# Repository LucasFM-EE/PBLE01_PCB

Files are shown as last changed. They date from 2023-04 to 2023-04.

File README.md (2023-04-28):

# PBLE01_PCB

Project designed for the discipline: Project Based Learning 01.

# Requirements
In this project, the board must match these requirements: 

### 1. Power Supply: 
- Support voltage input of 7V to 12V (DC);
- Provide regulated output of 5V;
- Use a LED to indicate that the board is powered.

### 2. Processing:
- Use a PIC18F4550 as a unit of processing and control;
- Use a pin header compatible with the ICSP standard, to program the microcontroller;
- Use a push-button to reset the microcontroller.

### 3. User interaction:
- Have a keyboard, composed by 5 push-buttons;
- Have a LCD display, which its luminosity is controlled by a trimmer;
- Have at least 4 LED's, which are able to signalize different states of the MCU;
- Have a potentiometer, which is used to provide analog data.

### 4. Peripherals
- Use a Real-Time Clock(RTC) - MCP7940;
- Contain 2 pairs of differential analog inputs(4 analog inputs). Each pair must provide a signal between 0V and 3V for the microcontroller; 
- Contain a analog output, made by a PWM signal;
- Contain a pin header that has the reference signal(GND), the power supply signal(VCC) and the microcontroller pins that aren't being used.

### 5. Communication
- Use a USB-Serial converter(MCP2200), to allow serial communication with the board.

# Functional Diagram
The following image shows a functional diagram of the board: 
Diagrama_PBLE01_english

# Board sections 
The following image shows the board, divided by the sections mentioned above: 
Board_sections

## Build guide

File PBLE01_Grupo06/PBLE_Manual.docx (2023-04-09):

PBLE01

Co-projeto de produtos eletrônicos

Manual

Grupo 6

# 1 Identificação dos integrantes

André Luís Oliveira de Almeida – 2019008624
João Roberto da Silva Couto - 2018000944

Lucas Ferreira Machado - 2019000537

# 2 Introdução

O objetivo da disciplina era certamente nos incluir no ramo do mercado de trabalho para projetos, protótipos e lançamentos de PCIs (placas de circuito impresso) e ideias correlacionadas, por promover uma experiência de mercado de trabalho, com o maior número possível de detalhes ao ponto que a disciplina em si não ensina quase nada novo, pois foi visto o que se requere no projeto em períodos anteriores.

As principais atividades a serem desenvolvidas durante o transcorrer da disciplina são o projeto da placa de circuito impresso, o desenvolvimento de programa embarcado de validação e a elaboração da documentação de projeto, etapas que não devem seguir um planejamento de inícios e términos, com etapas sendo discutidas e aprimoradas ao mesmo tempo, como se observa no desenho abaixo:

Figura 1 - Diagrama de avanço de tarefas

A etapa de projeto da placa de circuito ainda pode ser subdividida nas etapas de elaboração do esquema elétrico e de elaboração da PCI.

a documentação de projeto, a etapa que aqui vos instrui, a ser desenvolvido consiste em um manual a partir do qual é possível confeccionar e validar a placa de circuito impresso projetada. Para tanto, tal documento deve pormenorizar características do circuito elaborado, como seu esquema elétrico, suas características elétricas, os passos para sua validação bem como a relação de seus componentes e os fornecedores para estes.

Dizem que o engenheiro é aquele que aplica os conhecimentos dos cientistas, então este projeto, e consequentemente esta disciplina é a oportunidade perfeita para isso.

# 3 Esquema elétrico

A atividade de elaboração de esquema elétrico consiste em desenvolver a representação do circuito eletroeletrônicos relativo à placa de circuito impresso em projeto. Essa atividade costuma ser realizada por meio de ferramentas de desenvolvimento gráficas. Em linhas gerais, por meio dessas ferramentas, são elencados (e representados) os componentes eletrônicos discretos a fazerem parte da placa de circuito impresso em projeto e a interconexão entre eles.

## 3.1 Requisitos

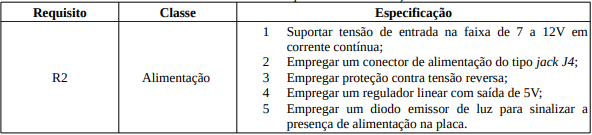
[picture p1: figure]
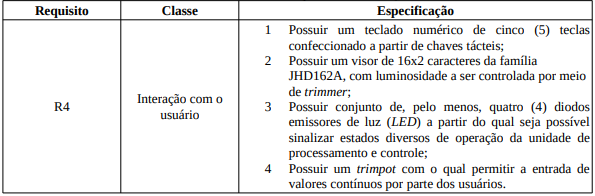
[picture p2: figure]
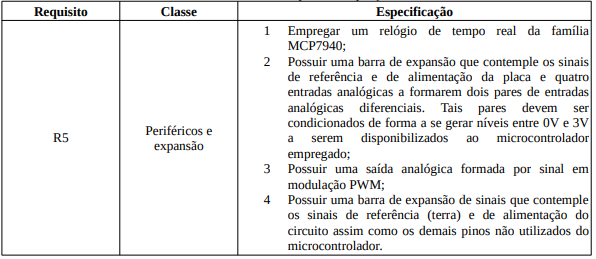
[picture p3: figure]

## 3.2 Circuito

O dispositivo almejado deve permitir, como principal meta, a interação entre diversas entradas e saídas com a unidade de processamento e os subcircuitos necessários para a efetivar a requisição do usuário.

Dentre entradas, algumas diretamente vindas do usuário (como o teclado), outras pré-definidas por estes (as entradas analógicas), outras vindas de terceiros (diferenciais) e ainda uma entrada do próprio dispositivo (RTC).

Dentre saídas, existem as que tanto visam informar o usuário (sinais de estados e LCD) quanto exportar um resultado (saída analógica).

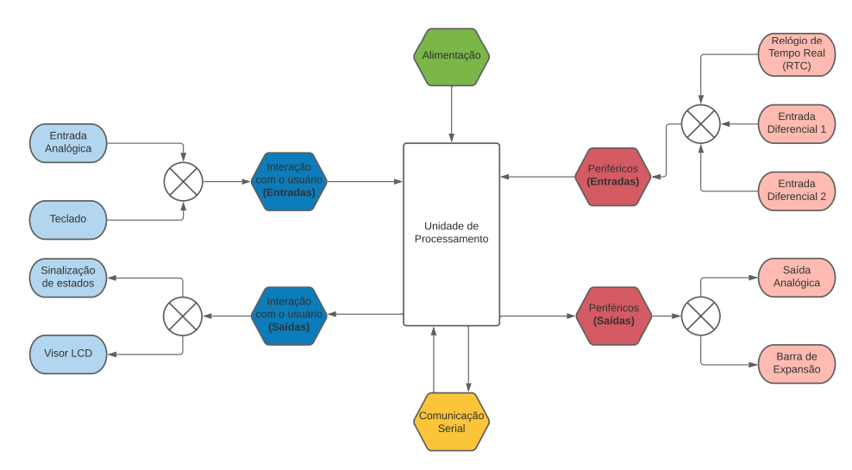
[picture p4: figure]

Figura 2 - representação em blocos funcionais do circuito

## 3.3 Esquemas elétricos

### 3.3.1 Unidade de processamento

A unidade de processamento é o “cérebro” do circuito, responsável não só pelos cálculos necessários, mas também pelo ritmo de todo o sistema. Desde as etapas de funcionamento de uma requisição até a forma de como serão demonstrados, e quando serão atualizados, os resultados da devida requisição. Confira abaixo o esquema elétrico

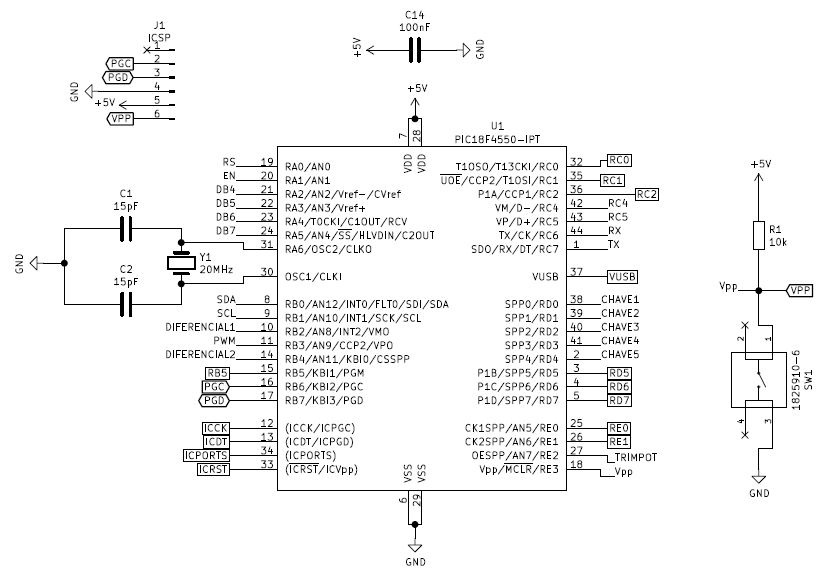
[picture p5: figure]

Figura 3- Esquema elétrico da unidade de processamento

### 3.3.2 Alimentação

A subdivisão da alimentação é responsável por suprir devidamente a demanda energética do sistema, reduzindo a tensão da fonte de alimentação externa para o nível necessário para o projeto em questão. Confira abaixo o esquema elétrico.

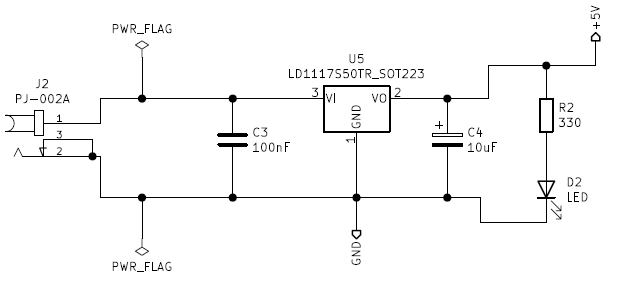
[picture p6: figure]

Figura 4- Esquema elétrico do subcircuito de alimentação

### 3.3.3 Relógio de Tempo Real

Esta subdivisão baseia-se em comunicação com o microcontrolador através do protocolo I2C e pode fornecer informações de data, hora, ano e afins, assim como pode também receber dados do PIC. Confira abaixo seu esquema elétrico.

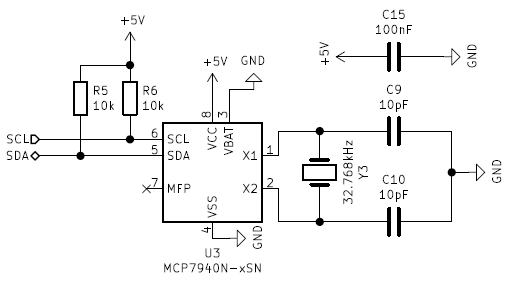
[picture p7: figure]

Figura 5- Esquema elétrico do relógio de tempo real

### 3.3.4 Teclado

O teclado, parte de uso exclusivo do usuário para com o usuário, é constituído por 5 botões e permitem que o usuário forneça valores digitais para o sistema, assim como configurar o que deve aparecer no LCD, que dado específico planeja obter, etc. Confira abaixo seu esquema elétrico.

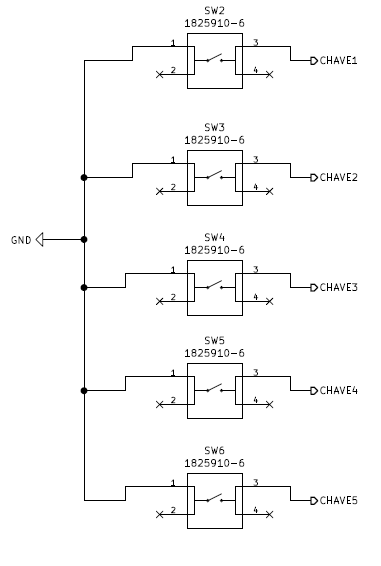
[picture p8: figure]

Figura 6- Esquema elétrico do Teclado

### 3.3.5 Sinalização

A sinalização para o usuário é formada por um conjunto de 4 leds e tem a função de fornecer uma sinalização luminosa sobre determinados pinos do microcontrolador. Confira abaixo seu esquema elétrico.

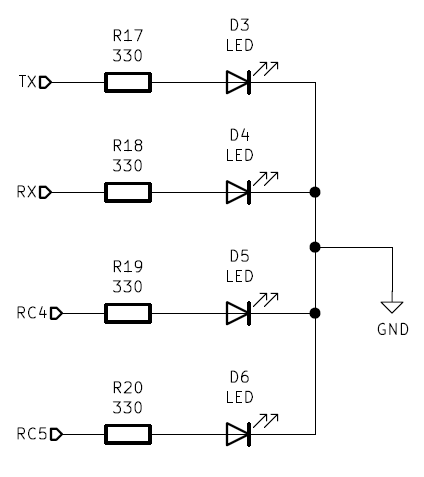
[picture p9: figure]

Figura 7- Esquema elétrico da sinalização luminosa

### 3.3.6 Entrada Analógica

Esta consiste em apenas 1 trimpot e tem a função de fornecer um valor analógico para o microcontrolador. Confira abaixo seu Esquema elétrico.

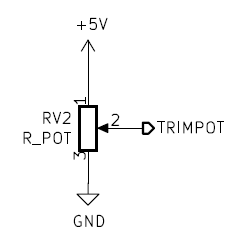
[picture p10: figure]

Figura 8- Esquema elétrico da entrada analógica

### 3.3.7 Entradas diferenciais

Este é constituída por dois circuitos que realizam a mesma função. Cada circuito possui duas entradas analógicas, que são subtraídas uma da outra e geram um sinal de tensão que é proporcional à diferença entre as duas entradas. Tal sinal é fornecido para o microcontrolador. (mais informações são encontradas no memorial de cálculo e especificações elétricas). Confira abaixo seus esquemas elétricos

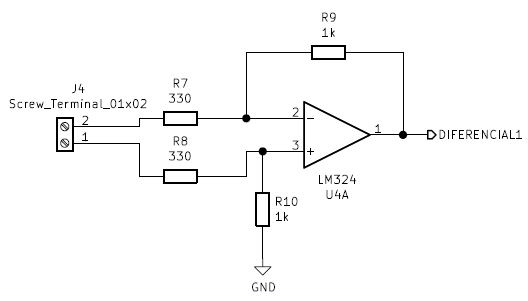
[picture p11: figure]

Figura 9- Esquema elétrico da entrada diferencial 1

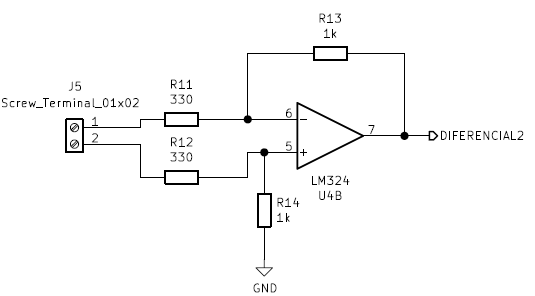
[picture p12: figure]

Figura 10 - Esquema elétrico da entrada diferencial 2

### 3.3.8 Saída Analógica

Essa parte é formada por um filtro passa-baixa e tem a função de fornecer um nível de tensão para o usuário. Esse nível de tensão é gerado a partir de uma saída PWM do microcontrolador. Confira abaixo seu esquema elétrico.

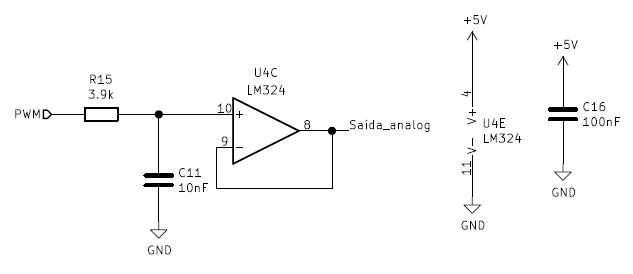
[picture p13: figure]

Figura 11- Esquema elétrico da saída analógica

### 3.3.9 Barras de expansão

uma barra contempla todos os pinos do microcontrolador que não estão sendo usados. A outra barra contempla os sinais de alimentação do circuito e a saída analógica que foi mostrada na saída analógica. Confira abaixo seu esquema elétrico.

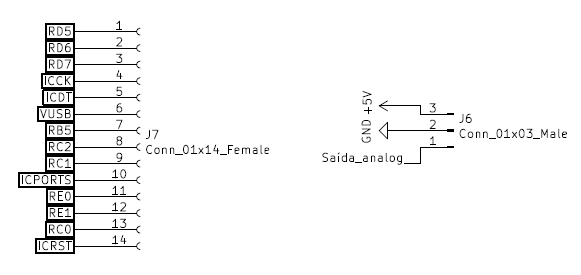
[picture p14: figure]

Figura 12- esquema elétrico das barras de expansão

### 3.3.10 Comunicação serial

Esse sub-circuito é principalmente constituído por um conversor USB-serial e um conector USB. Ele tem a função de estabelecer a comunicação entre o microcontrolador e, por exemplo, um computador que esteja conectado à placa através de um cabo USB. Confira seu esquema elétrico na imagem abaixo.

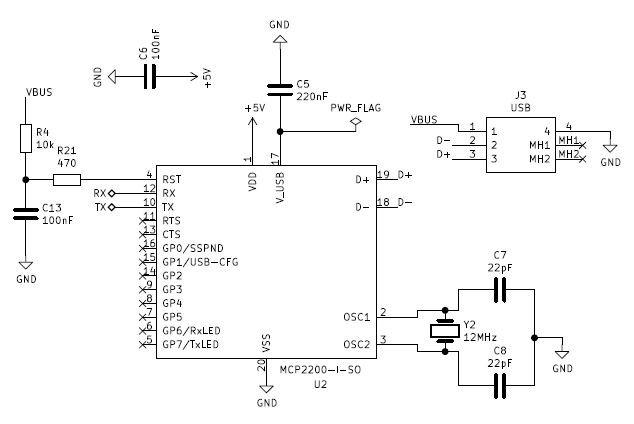
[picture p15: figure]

Figura 13- Esquema elétrico do subcircuito de comunicação serial

### 3.3.11 Visor LCD

Essa parte é constituída por um visor de cristal líquido e um trimmer. Tem o objetivo de fornecer informações em formato de texto para o usuário sobre algum estado do sistema. O trimmer serve para alterar o contraste do visor. Confira abaixo seu esquema elétrico

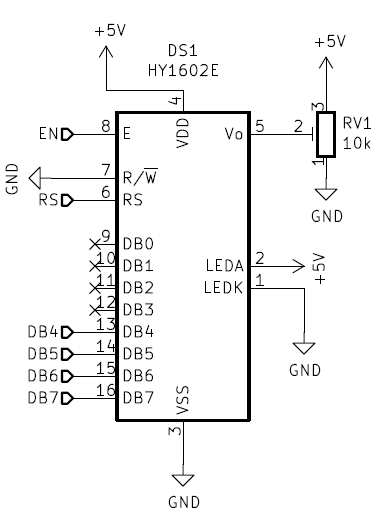
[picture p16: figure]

Figura 14- Esquema elétrico do visor LCD

## 3.4 Memorial de cálculos

### 3.4.1 Entradas diferenciais

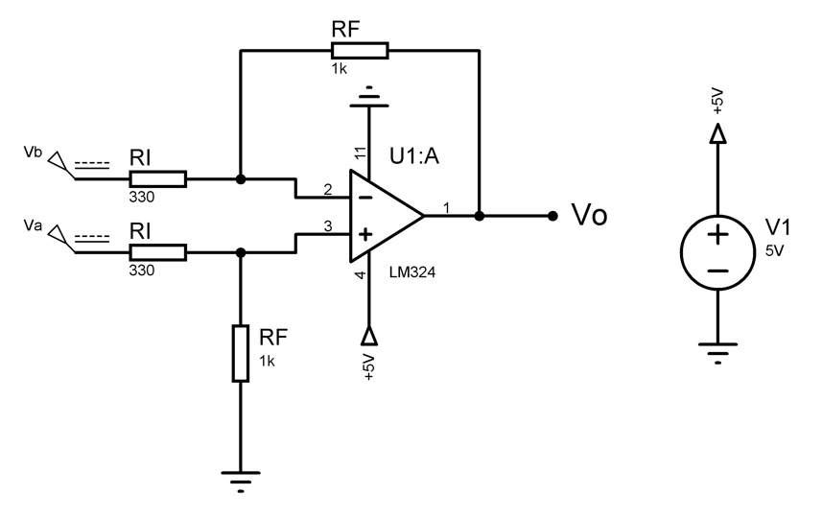
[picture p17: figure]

Ambas entradas diferenciais apresentam o circuito apresentado acima. A equação para a tensão de saída é mostrada abaixo:

V_O = (R_F)/(R_I)*(V_A -V_B )

Já que a saída deveria variar de 0 a 3V, o ganho escolhido foi de:

(R_F)/(R_I)= 1000/330=3,03

A partir desse ganho, a entrada diferencial ( V_A -V_B ) poderia variar de 0 a 1V. Porém, a tensão inferior de saturação do amplificador operacional escolhido é de 0.5V (característica inerente ao amplificador), e por causa disso, se a entrada diferencial for menor do que aproximadamente 0.17V, a saída ficará limitada ao valor de 0.5V, como é mostrado a seguir:

V_O = 3,03*(0,17)= 0,51 V

Conclusão:

Para (V_A -V_B ) variando de 0.17V a 1V

V_O vai variar de 0.5V a 3V

### 3.4.2 Saída Analógica

Projeto do filtro passa-baixa:

A frequência de corte escolhida para o filtro foi de 4 kHz. Para descobrir a frequência do PWM, foi usada a seguinte relação (onde f_C é a frequência de corte e K é uma constante):

f_(PWM) =K*f_C

Escolhendo uma constante K=25, com o objetivo de gerar uma frequência bem alta para o PWM, chegou-se ao seguinte resultado:
f_(PWM) =K*f_C f_(PWM) =25*4000 f_(PWM) =100 kHz

A seguir, foram calculados os valores de R e C:

R*C=1/(2*π*f_C) R*C=39,78*10^(-6)

Escolhendo um R = 3,9kΩ (valor comercial), foi encontrado o valor de C:

C=(39,78*10^(-6))/3900 C=10,2*10^(-9)

Logo, os valores finais comerciais escolhidos e a frequência do PWM são resumidos abaixo:

R=3,9 kΩ

C=10 nF

f_(PWM) =100 kHz

## 3.5 Relatório de verificação de erros de projeto

O relatório de erros do esquema elétrico não apresentou nenhum aviso.

# 4 Placa de circuito impresso

O projeto da placa de circuito impresso se trata de especificar como deve ocorrer a transposição do esquema elétrico desenvolvido para uma PCI real. Nesta etapa, os componentes que fazem parte do circuito são associados às pegadas (footprints), e suas interconexões, às trilhas de sinais. Ainda nesta etapa, é também produzida uma lista de compra para os componentes eletroeletrônicos que fazem parte da placa de circuito impresso projetada.

## 4.1 Requisitos

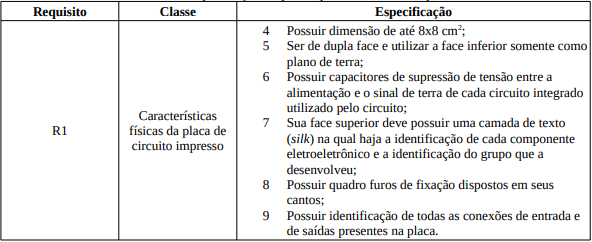
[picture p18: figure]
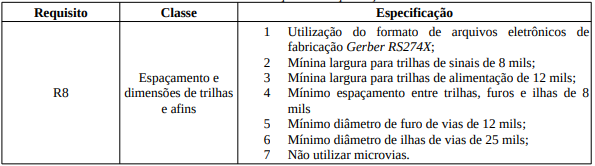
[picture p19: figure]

## 4.2 Desenho da placa de circuito impresso

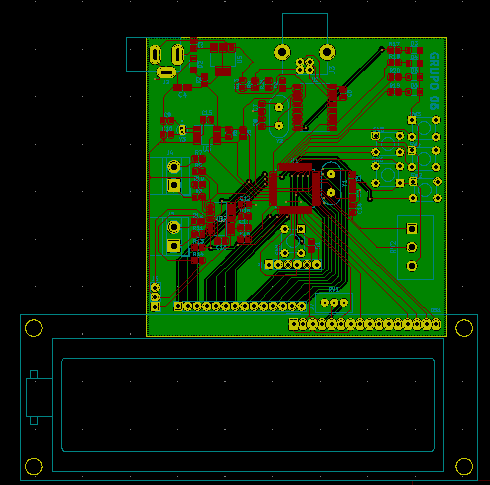
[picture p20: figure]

Figura 15- Desenho da PCI

## 4.3 Visão tridimensional do circuito projetado

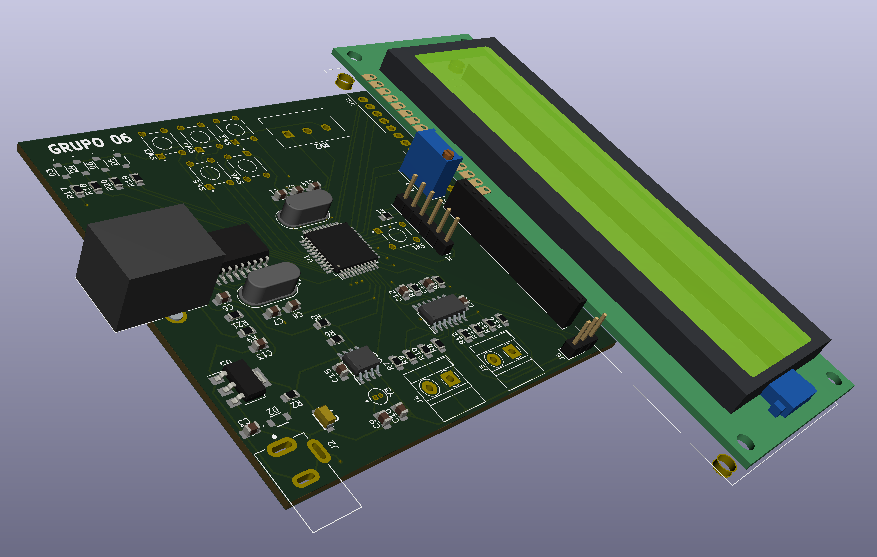
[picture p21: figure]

Figura 16- Visão tridimensional da PCI

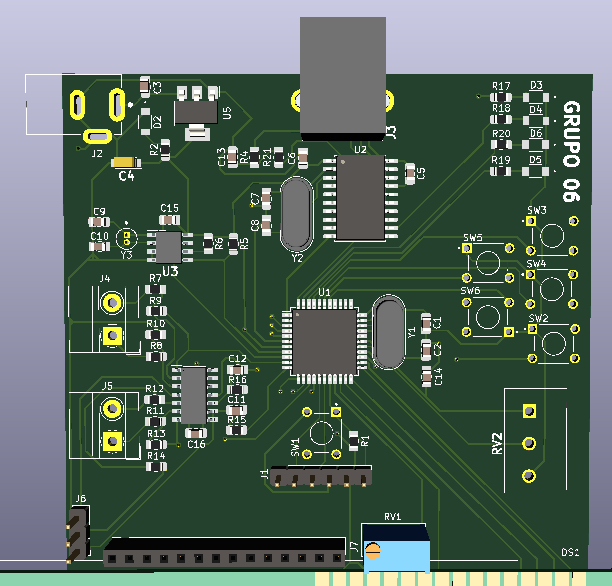
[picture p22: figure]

Figura 17- Visão da parte frontal da PCI

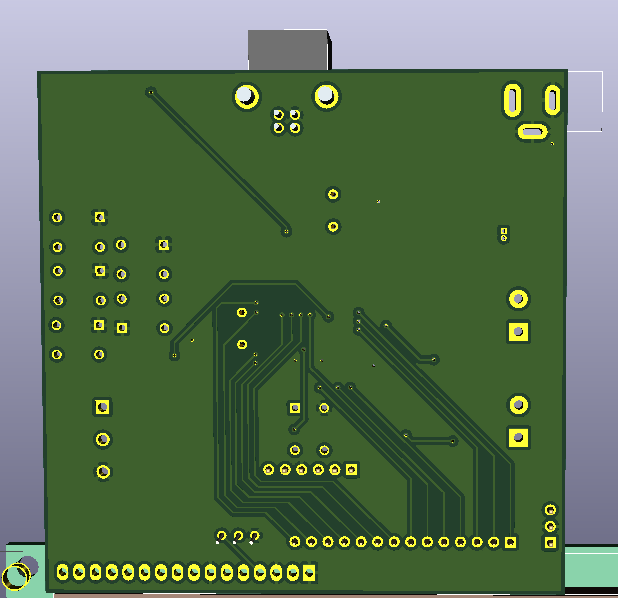
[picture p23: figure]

Figura 18- Visão traseira da PCI

## 4.4 Relatório de verificação de erros de projeto

** Drc report for C:\Users\Lucas F. Machado\Desktop\PBLE01\PBLE01_Grupo06\PBLE01.kicad_pcb **

** Created on **

** Found 4 DRC errors **

ErrType(19): Ilha muito próxima a ilha

@(115,570 mm, 71,942 mm): Ilha 1 de Y3 em Todas as camadas de cobre

@(115,570 mm, 73,042 mm): Ilha 2 de Y3 em Todas as camadas de cobre

ErrType(45): Sobreposição de pátios

@(147,053 mm, 56,363 mm): Footprint J3 em F.Cu

@(142,314 mm, 60,325 mm): Footprint C6 em F.Cu

ErrType(45): Sobreposição de pátios

@(147,053 mm, 56,363 mm): Footprint J3 em F.Cu

@(138,633 mm, 60,198 mm): Footprint R21 em F.Cu

ErrType(45): Sobreposição de pátios

@(176,847 mm, 98,770 mm): Footprint RV2 em F.Cu

@(161,064 mm, 93,467 mm): Footprint C14 em F.Cu

** Found 0 unconnected pads **

** End of Report **

# 5 Especificações elétricas

## 5.1 Níveis de alimentação suportados

A placa suporta fonte de corrente contínua externa que seja entre 7V a 15V.

Tensões inferiores a 7V também podem ser aplicadas, porém não é recomendado, pois o sistema pode não operar da forma correta.

## 5.2 Faixa de níveis de consumo estimadas

Estamos usando 22 portas do microcontrolador para acionar saídas e ler entradas. Como cada porta tem a capacidade de drenar ou fornecer 20mA de corrente, então, considerando o pior caso (onde todas as portas estão operando com o máximo de sua capacidade e ao mesmo tempo), o sistema vai consumir aproximadamente:

22 portas x 20mA = 440mA

## 5.3 Correntes e tensões máximas de entrada

Entradas Diferenciais → 0 a 32V em cada entrada de cada par diferencial.

## 5.4 Correntes e tensões máximas de saída

Saída analógica → 0,5V a 4,5V (é limitada pela saída PWM).

# 6 Programa embarcado de validação

Na etapa de desenvolvimento do programa embarcado, é desenvolvido um sequenciamento de ações mínimo a ser utilizado exclusivamente para se testar as funcionalidades básicas de componentes do circuito impresso projetado, como, por exemplo, para se verificar se uma unidade de processamento é capaz de detectar e identificar interações com demais componentes do circuito. Esse programa embarcado não corresponde ao programa final de aplicação da placa desenvolvida, mas apenas a um subproduto de projeto utilizado exclusivamente para se realizar certas validações de projeto.

# 7 Montagem

## 7.1 Lista de compras

ITEM | QUANTIDADE | FABRICANTE | PART NUMBER
Amplificador Operacional | 3 | On Semi | LM324DG
Capacitor 100nF | 6 | Diversos | 445-175390-1-ND
Capacitor 10nF | 1 | Diversos | C321C103J3G5TA-ND
Capacitor 10pF | 2 | Diversos | 399-7815-2-ND
Capacitor 10uF | 2 | Diversos | 493-1057-ND
Capacitor 15pF | 2 | Diversos | 399-4152-ND
Capacitor 220nF | 1 | Diversos | C356C224K1G5TA-ND
Capacitor 22pF | 2 | Diversos | 399-4220-ND
Chaves tácteis | 6 | TE Connectivity | 1825910-6
Con. Barra de expansão | 1 | TE Connectivity | A31112-ND
Con. Entradas diferenciais | 2 | On Shore Inc. | ED2580-ND
Conector alimentação | 1 | CUI Devices | PJ-002A CUI
Cristal de 12KHZ | 1 | CTS Electronic | CTX1077-ND
Cristal de 20KHZ | 1 | CTS Electronic | CTX1106-ND
Cristal de 32.768KHZ | 1 | ABRACON | 535-9034-ND
LEDs | 5 | Lite On | 160-1169-2-ND
Microprocessador | 1 | Microchip | PIC18F4550-I/PT-ND
Regulador de tensão | 1 | STMicroelectronics | 497-1238-2-ND
Relógio de tempo real | 1 | Microchip | MCP7940N-I/SN
Resistor 10k Ohms | 4 | Diversos | 10KQBK-ND
Resistor 1k Ohms | 4 | Diversos | S1KHTR-ND
Resistor 330 Ohms | 9 | Diversos | 330QBK-ND
Resistor 3k9 Ohms | 1 | Diversos | 3.9KW-2-ND
Resistor 470 Ohms | 1 | Diversos | 470QBK-ND
Transceptor USB-serial | 1 | Microchip | MCP2200-I/SO-ND
Trimmer de 10k | 1 | Bourns Inc | 3296W-1-103RLFTR-ND
Trimpot 10k | 1 | TT Electronics | P160KN-0QC15B100K
Visor LCD | 1 | Precise | HY1602E

## 7.2 Análise de Custos

ID NO E.Elétrico | FORNECEDOR | PREÇO UNITÁRIO
Diversos | Digikey | $1.25
C11 | Digikey | $0.17
Diversos | Digikey | $0.20
Diversos | Digikey | $0.28
Diversos | Digikey | $0.55
C05 | Digikey | $1.67
Diversos | Digikey | $0.20
Diversos | Digikey | $0.11
J7 | Digikey | $0.25
J4, J5 | Digikey | $0.76
J2 | Digikey | $0.60
Y2 | Digikey | $0.36
Y1 | Digikey | $0.36
Y3 | Digikey | $0.32
Diversos | Digikey | $0.31
U1 | Digikey | $6.66
U5 | Digikey | $0.54
U3 | Digikey | $0.80
Diversos | Digikey | $0.10
Diversos | Digikey | $0.10
Diversos | Digikey | $0.10
R15 | Digikey | $0.44
R21 | Digikey | $0.10
U2 | Digikey | $2.16
RV1 | Digikey | $1.81
RV2 | Digikey | $0.43
DS1 | AliExpress | $3.39

Não foi possível comportar a tabela toda no manual, então ela estará em anexo caso necessário.

# 8 Anexos

## 8.1 Código-fonte do programa de validação

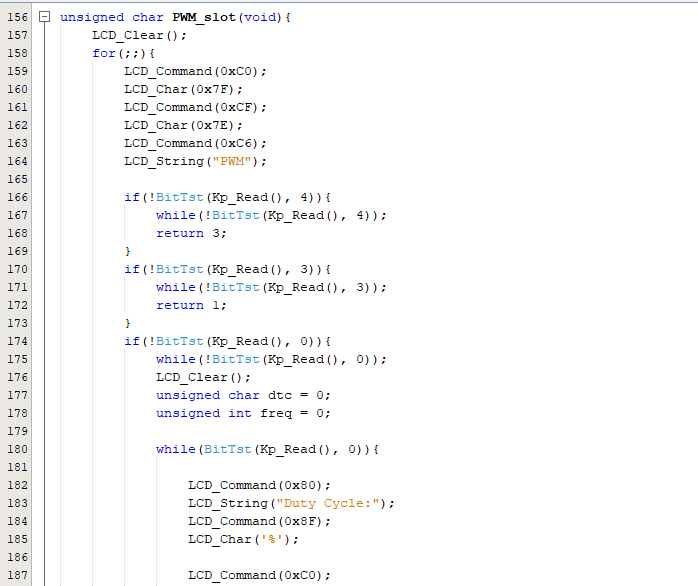
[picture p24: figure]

## 8.2 Programas utilizados

FERRAMENTA | VERSÃO | USO
KiCad | 5.1.10 | Desenvolvimento do esquema elétrico e PCI
Proteus | 8.5 | Simulação do sistema
MPLab | 5.20 | Produção do embarcado de validação

# 9 Bibliografia

- Link para cálculo do filtro disponível em: http://ww1.microchip.com/downloads/en/AppNotes/00538c.pdf
- Aulas e proposta de projeto da disciplina, disponível em: https://sigaa.unifei.edu.br/sigaa/ava/index.jsf
- Datasheet do amplificador disponível em: https://www.ti.com/product/LM324LV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 (https://www.ti.com/product/LM324LV?DCM=yes&dclid=CN73ktOmpfICFUomuQYdCucHcQ)
- Datasheet do microprocessador disponível em: https://www.microchip.com/en-us/product/PIC18F4550
- Datasheet do transceptor disponível em: https://www.microchip.com/en-us/product/MCP2200
- Datasheet do relógio disponível em: https://www.microchip.com/en-us/product/MCP7940N

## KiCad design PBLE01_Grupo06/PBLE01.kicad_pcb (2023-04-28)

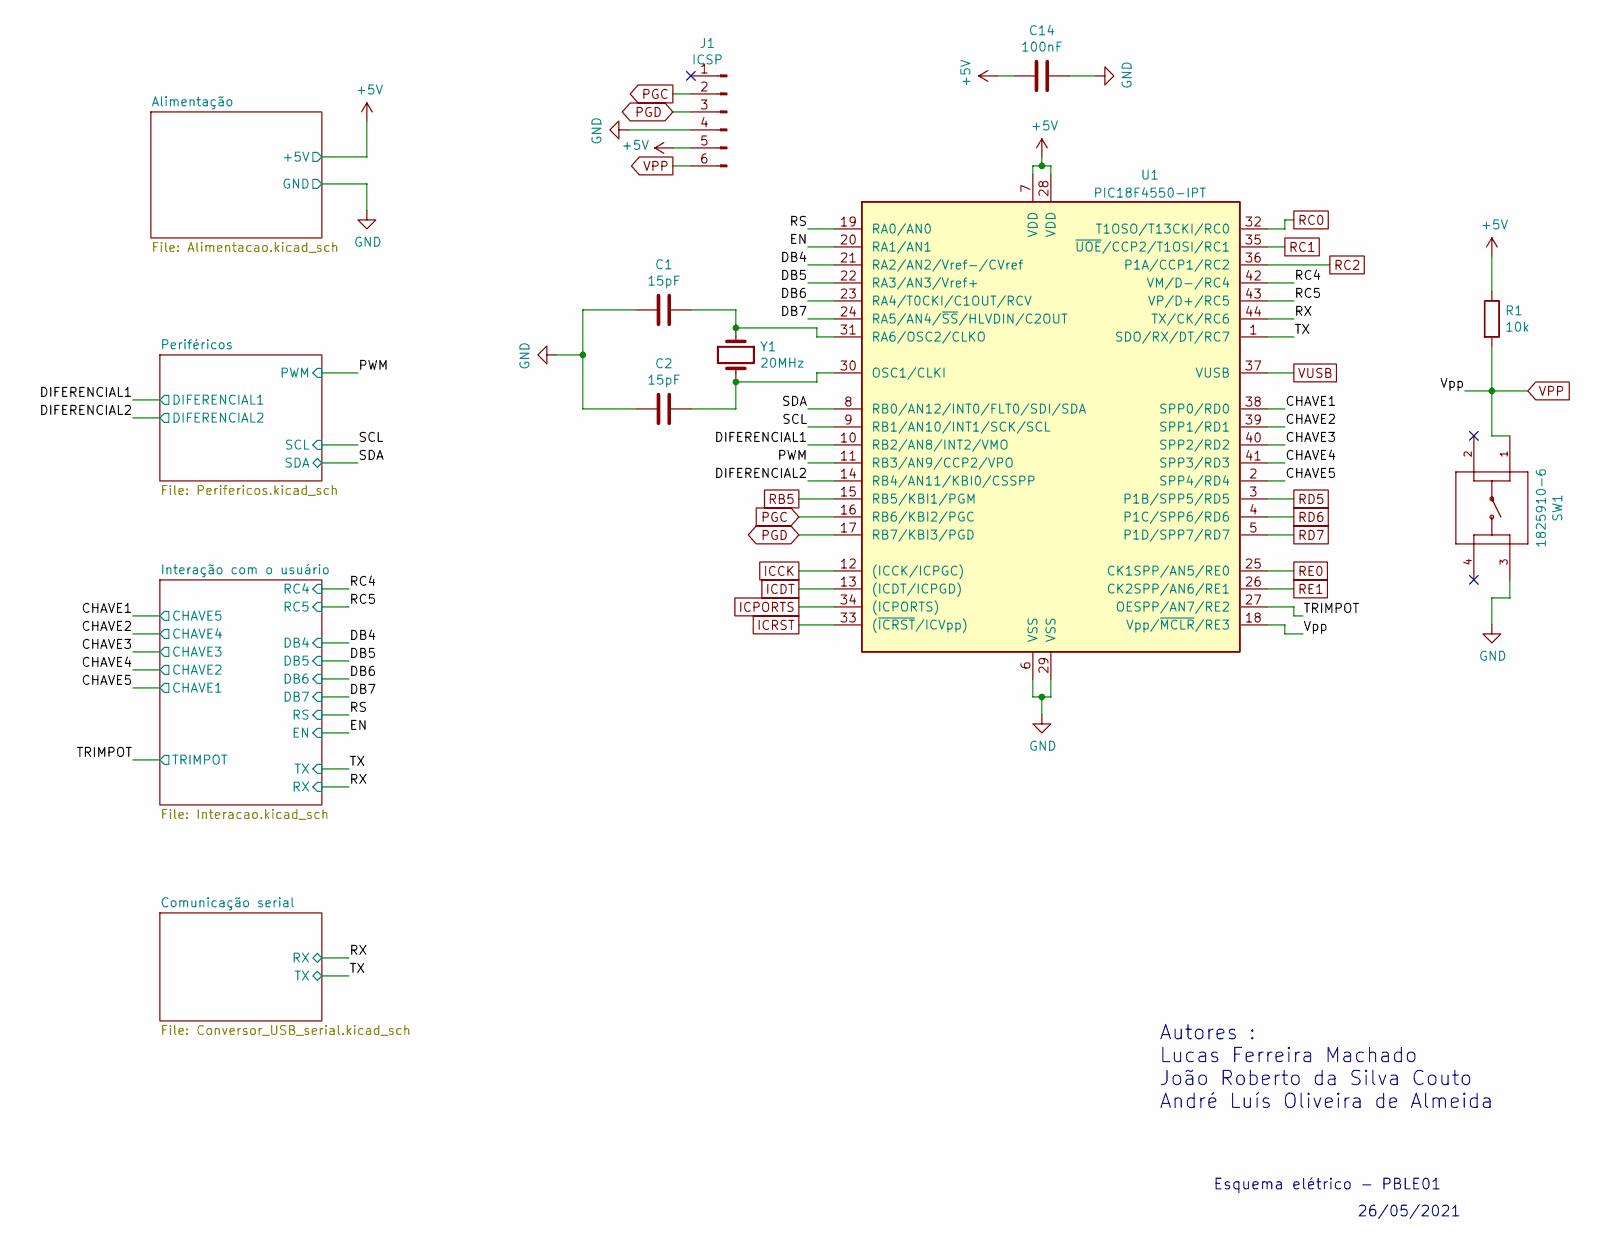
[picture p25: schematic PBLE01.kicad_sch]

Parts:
C1, C2: 15pF; C_0805_2012Metric_Pad1.18x1.45mm_HandSolder
C14: 100nF; C_0805_2012Metric_Pad1.18x1.45mm_HandSolder
J1: ICSP; PinHeader_1x06_P2.54mm_Vertical
R1: 10k; R_0805_2012Metric_Pad1.20x1.40mm_HandSolder
SW1: 1825910-6; SW_1825910-6-4
U1: PIC18F4550-IPT; TQFP-44_10x10mm_P0.8mm
Y1: 20MHz; Crystal_HC49-4H_Vertical

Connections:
+5V: C14.1, J1.5, R1.1, U1.7 (VDD), U1.28 (VDD); also elsewhere on the board
/CHAVE1: U1.38 (SPP0/RD0); also elsewhere on the board
/CHAVE2: U1.39 (SPP1/RD1); also elsewhere on the board
/CHAVE3: U1.40 (SPP2/RD2); also elsewhere on the board
/CHAVE4: U1.41 (SPP3/RD3); also elsewhere on the board
/CHAVE5: U1.2 (SPP4/RD4); also elsewhere on the board
/DB4: U1.21 (RA2/AN2/Vref-/CVref); also elsewhere on the board
/DB5: U1.22 (RA3/AN3/Vref+); also elsewhere on the board
/DB6: U1.23 (RA4/T0CKI/C1OUT/RCV); also elsewhere on the board
/DB7: U1.24 (RA5/AN4/~SS/HLVDIN/C2OUT); also elsewhere on the board
/DIFERENCIAL1: U1.10 (RB2/AN8/INT2/VMO); also elsewhere on the board
/DIFERENCIAL2: U1.14 (RB4/AN11/KBI0/CSSPP); also elsewhere on the board
/EN: U1.20 (RA1/AN1); also elsewhere on the board
/PWM: U1.11 (RB3/AN9/CCP2/VPO); also elsewhere on the board
/RC4: U1.42 (VM/D-/RC4); also elsewhere on the board
/RC5: U1.43 (VP/D+/RC5); also elsewhere on the board
/RS: U1.19 (RA0/AN0); also elsewhere on the board
/RX: U1.44 (TX/CK/RC6); also elsewhere on the board
/SCL: U1.9 (RB1/AN10/INT1/SCK/SCL); also elsewhere on the board
/SDA: U1.8 (RB0/AN12/INT0/FLT0/SDI/SDA); also elsewhere on the board
/TRIMPOT: U1.27 (OESPP/AN7/RE2); also elsewhere on the board
/TX: U1.1 (SDO/RX/DT/RC7); also elsewhere on the board
ICCK: U1.12 ((ICCK/ICPGC)); also elsewhere on the board
ICDT: U1.13 ((ICDT/ICPGD)); also elsewhere on the board
ICPORTS: U1.34 ((ICPORTS)); also elsewhere on the board
ICRST: U1.33 ((~ICRST/ICVpp)); also elsewhere on the board
unnamed: C1.2, U1.31 (RA6/OSC2/CLKO), Y1.1
unnamed: C2.2, U1.30 (OSC1/CLKI), Y1.2
PGC: J1.2, U1.16 (RB6/KBI2/PGC)
PGD: J1.3, U1.17 (RB7/KBI3/PGD)
RB5: U1.15 (RB5/KBI1/PGM); also elsewhere on the board
RC0: U1.32 (T1OSO/T13CKI/RC0); also elsewhere on the board
RC1: U1.35 (~UOE/CCP2/T1OSI/RC1); also elsewhere on the board
RC2: U1.36 (P1A/CCP1/RC2); also elsewhere on the board
RD5: U1.3 (P1B/SPP5/RD5); also elsewhere on the board
RD6: U1.4 (P1C/SPP6/RD6); also elsewhere on the board
RD7: U1.5 (P1D/SPP7/RD7); also elsewhere on the board
RE0: U1.25 (CK1SPP/AN5/RE0); also elsewhere on the board
RE1: U1.26 (CK2SPP/AN6/RE1); also elsewhere on the board
VPP: J1.6, R1.2, SW1.1, U1.18 (Vpp/~MCLR/RE3)
VUSB: U1.37 (VUSB); also elsewhere on the board

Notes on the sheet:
Esquema elétrico - PBLE01
Autores : Lucas Ferreira Machado João Roberto da Silva Couto André Luís Oliveira de Almeida
26/05/2021

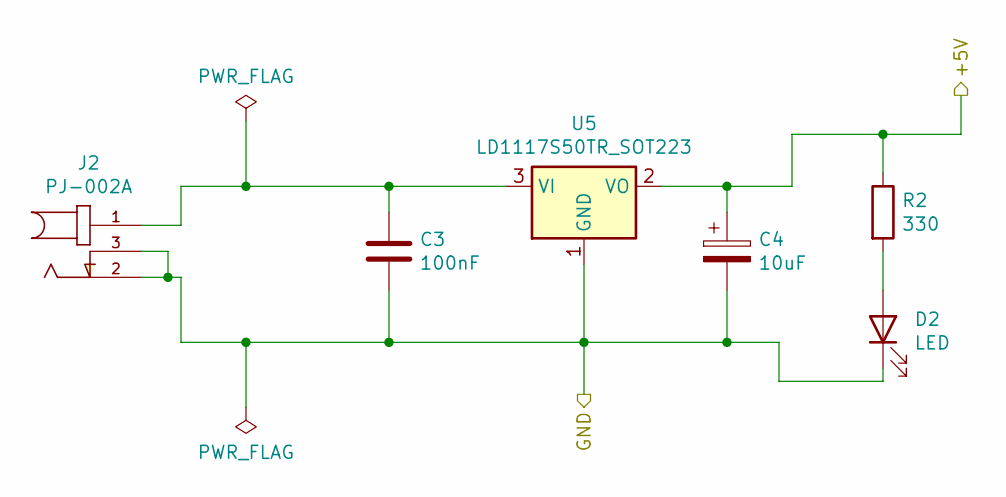
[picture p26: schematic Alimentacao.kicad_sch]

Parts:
C3: 100nF; C_0805_2012Metric_Pad1.18x1.45mm_HandSolder
C4: 10uF; CAPPM3216X180N
D2: LED; LTST-C150GKT
J2: PJ-002A; CUI_PJ-002A
R2: 330; R_0805_2012Metric_Pad1.20x1.40mm_HandSolder
U5: LD1117S50TR_SOT223; SOT-223-3_TabPin2

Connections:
+5V: C4.1, R2.1, U5.2 (VO); also elsewhere on the board
unnamed: C3.1, J2.1, U5.3 (VI)
unnamed: D2.2 (A), R2.2

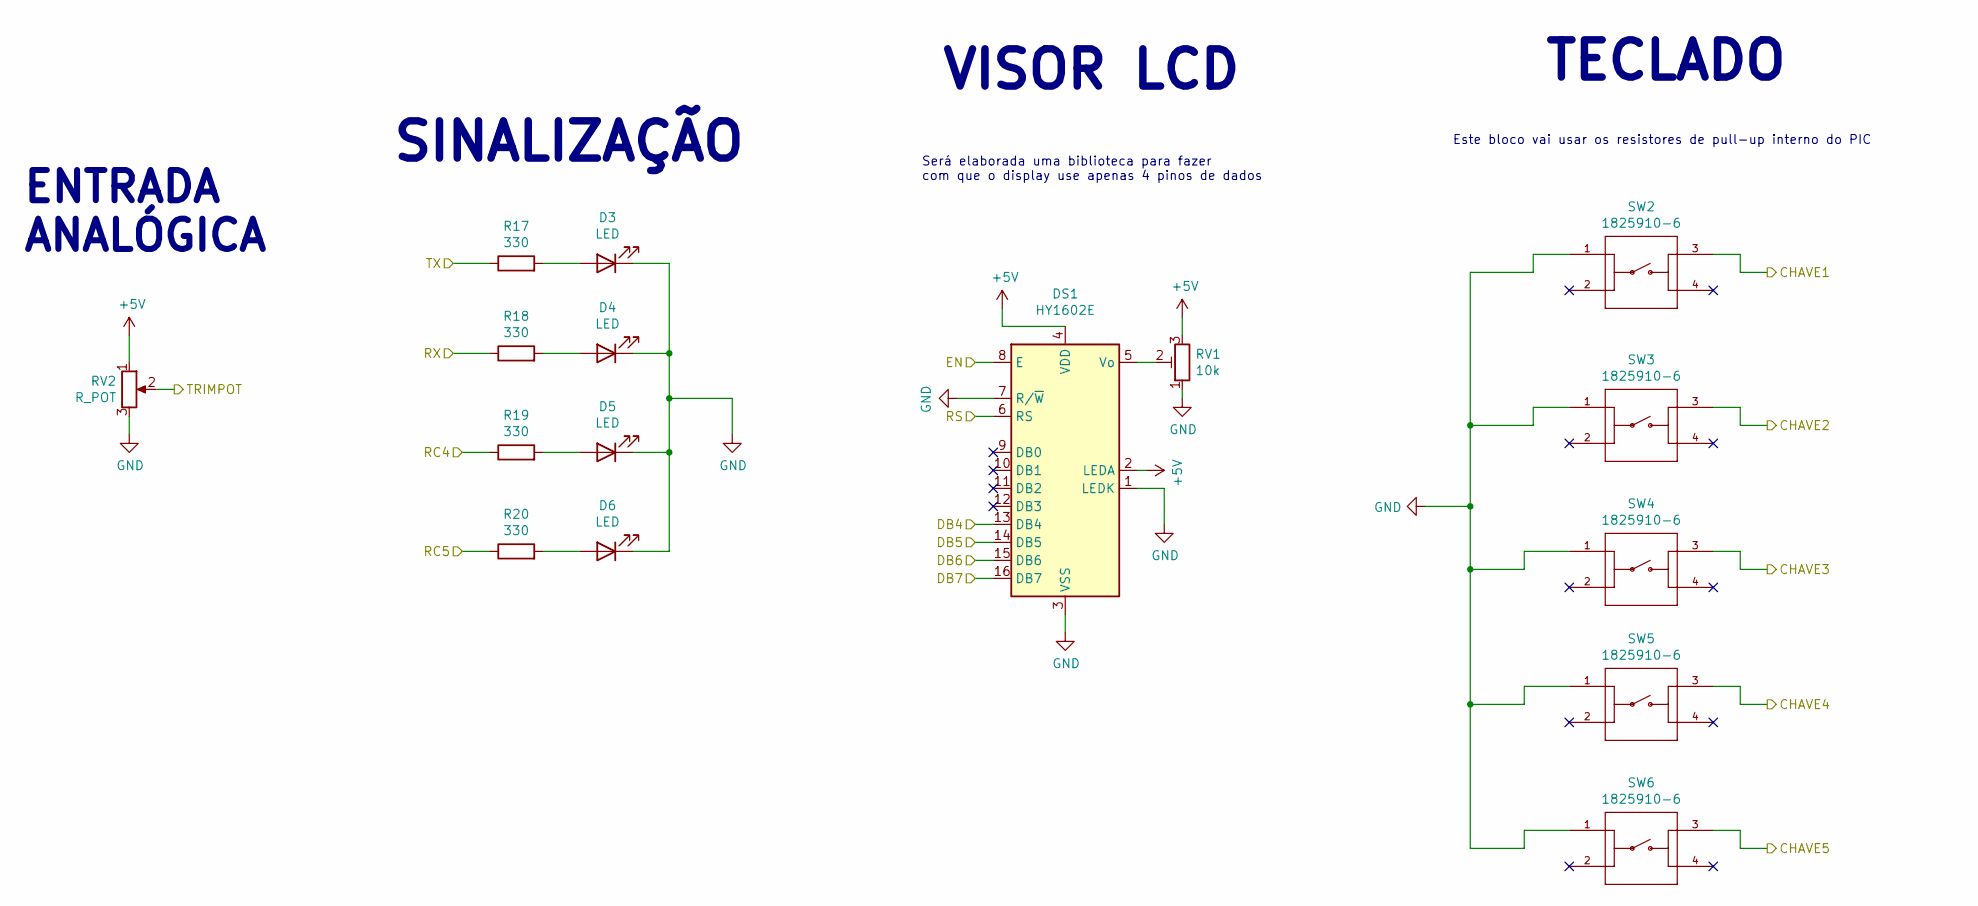
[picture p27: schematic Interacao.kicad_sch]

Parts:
D3, D4, D5, D6: LED; LTST-C150GKT
DS1: HY1602E
R17, R18, R19, R20: 330; R_0805_2012Metric_Pad1.20x1.40mm_HandSolder
RV1: 10k; Potentiometer_Bourns_3296W_Vertical
RV2: R_POT; P160KN0QC15B100K
SW2, SW3, SW4, SW5, SW6: 1825910-6; SW_1825910-6-4

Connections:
+5V: DS1.2 (LEDA), DS1.4 (VDD), RV1.3, RV2.1; also elsewhere on the board
/CHAVE1: SW6.3; also elsewhere on the board
/CHAVE2: SW5.3; also elsewhere on the board
/CHAVE3: SW4.3; also elsewhere on the board
/CHAVE4: SW3.3; also elsewhere on the board
/CHAVE5: SW2.3; also elsewhere on the board
/DB4: DS1.13 (DB4); also elsewhere on the board
/DB5: DS1.14 (DB5); also elsewhere on the board
/DB6: DS1.15 (DB6); also elsewhere on the board
/DB7: DS1.16 (DB7); also elsewhere on the board
/EN: DS1.8 (E); also elsewhere on the board
/RC4: R19.1; also elsewhere on the board
/RC5: R20.1; also elsewhere on the board
/RS: DS1.6 (RS); also elsewhere on the board
/RX: R18.1; also elsewhere on the board
/TRIMPOT: RV2.2; also elsewhere on the board
/TX: R17.1; also elsewhere on the board
unnamed: D3.2 (A), R17.2
unnamed: D4.2 (A), R18.2
unnamed: D5.2 (A), R19.2
unnamed: D6.2 (A), R20.2
unnamed: DS1.5 (Vo), RV1.2

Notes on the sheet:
Será elaborada uma biblioteca para fazer com que o display use apenas 4 pinos de dados
ENTRADA ANALÓGICA
VISOR LCD
TECLADO
Este bloco vai usar os resistores de pull-up interno do PIC
SINALIZAÇÃO

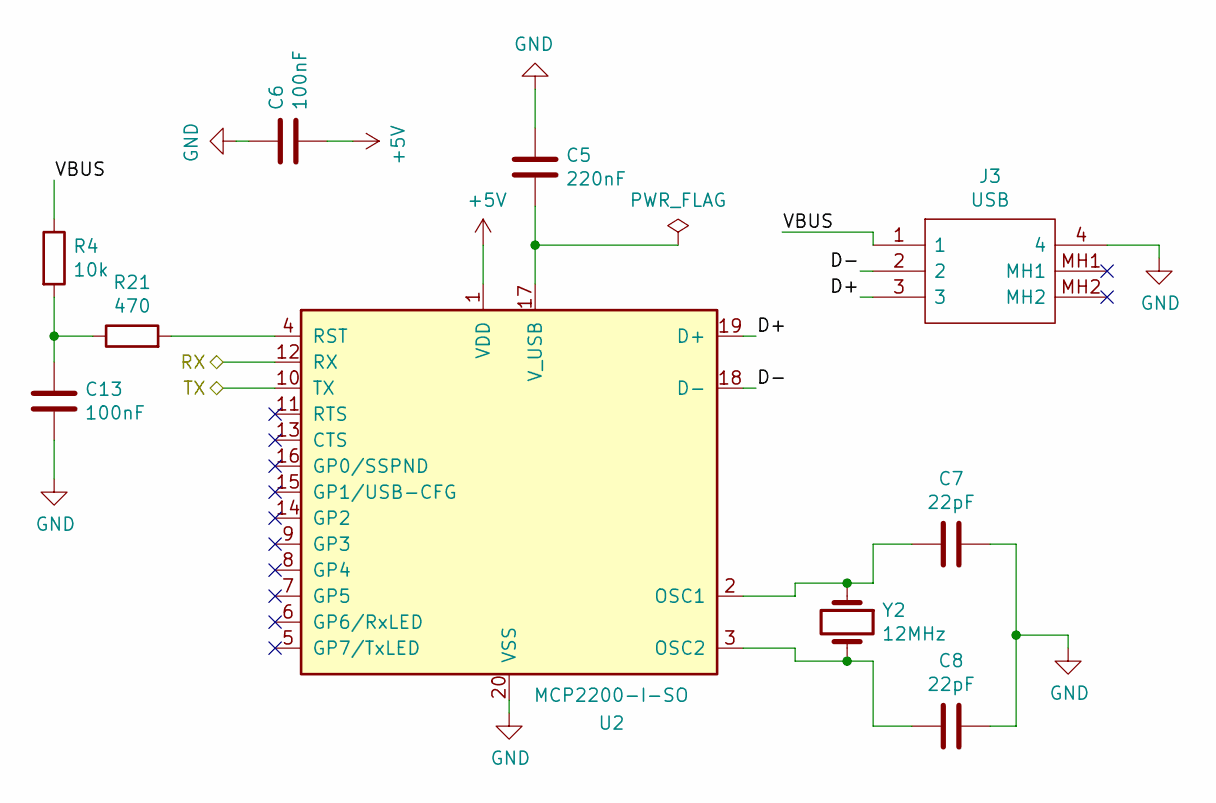
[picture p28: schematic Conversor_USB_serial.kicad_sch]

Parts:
C5: 220nF; C_0805_2012Metric_Pad1.18x1.45mm_HandSolder
C6, C13: 100nF; C_0805_2012Metric_Pad1.18x1.45mm_HandSolder
C7, C8: 22pF; C_0805_2012Metric_Pad1.18x1.45mm_HandSolder
J3: USB; 8974300490000000; Mouser Part Number 575-8974349
R4: 10k; R_0805_2012Metric_Pad1.20x1.40mm_HandSolder
R21: 470; R_0805_2012Metric_Pad1.20x1.40mm_HandSolder
U2: MCP2200-I-SO; SOIC-20W_7.5x12.8mm_P1.27mm
Y2: 12MHz; Crystal_HC49-4H_Vertical

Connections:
+5V: C6.2, U2.1 (VDD); also elsewhere on the board
/Comunicação serial /VBUS: J3.1, R4.1
/RX: U2.12 (RX); also elsewhere on the board
/TX: U2.10 (TX); also elsewhere on the board
unnamed: C5.2, U2.17 (V_USB)
unnamed: C7.2, U2.2 (OSC1), Y2.1
unnamed: C8.1, U2.3 (OSC2), Y2.2
unnamed: C13.1, R4.2, R21.1
unnamed: J3.2, U2.18 (D-)
unnamed: J3.3, U2.19 (D+)
unnamed: R21.2, U2.4 (RST)

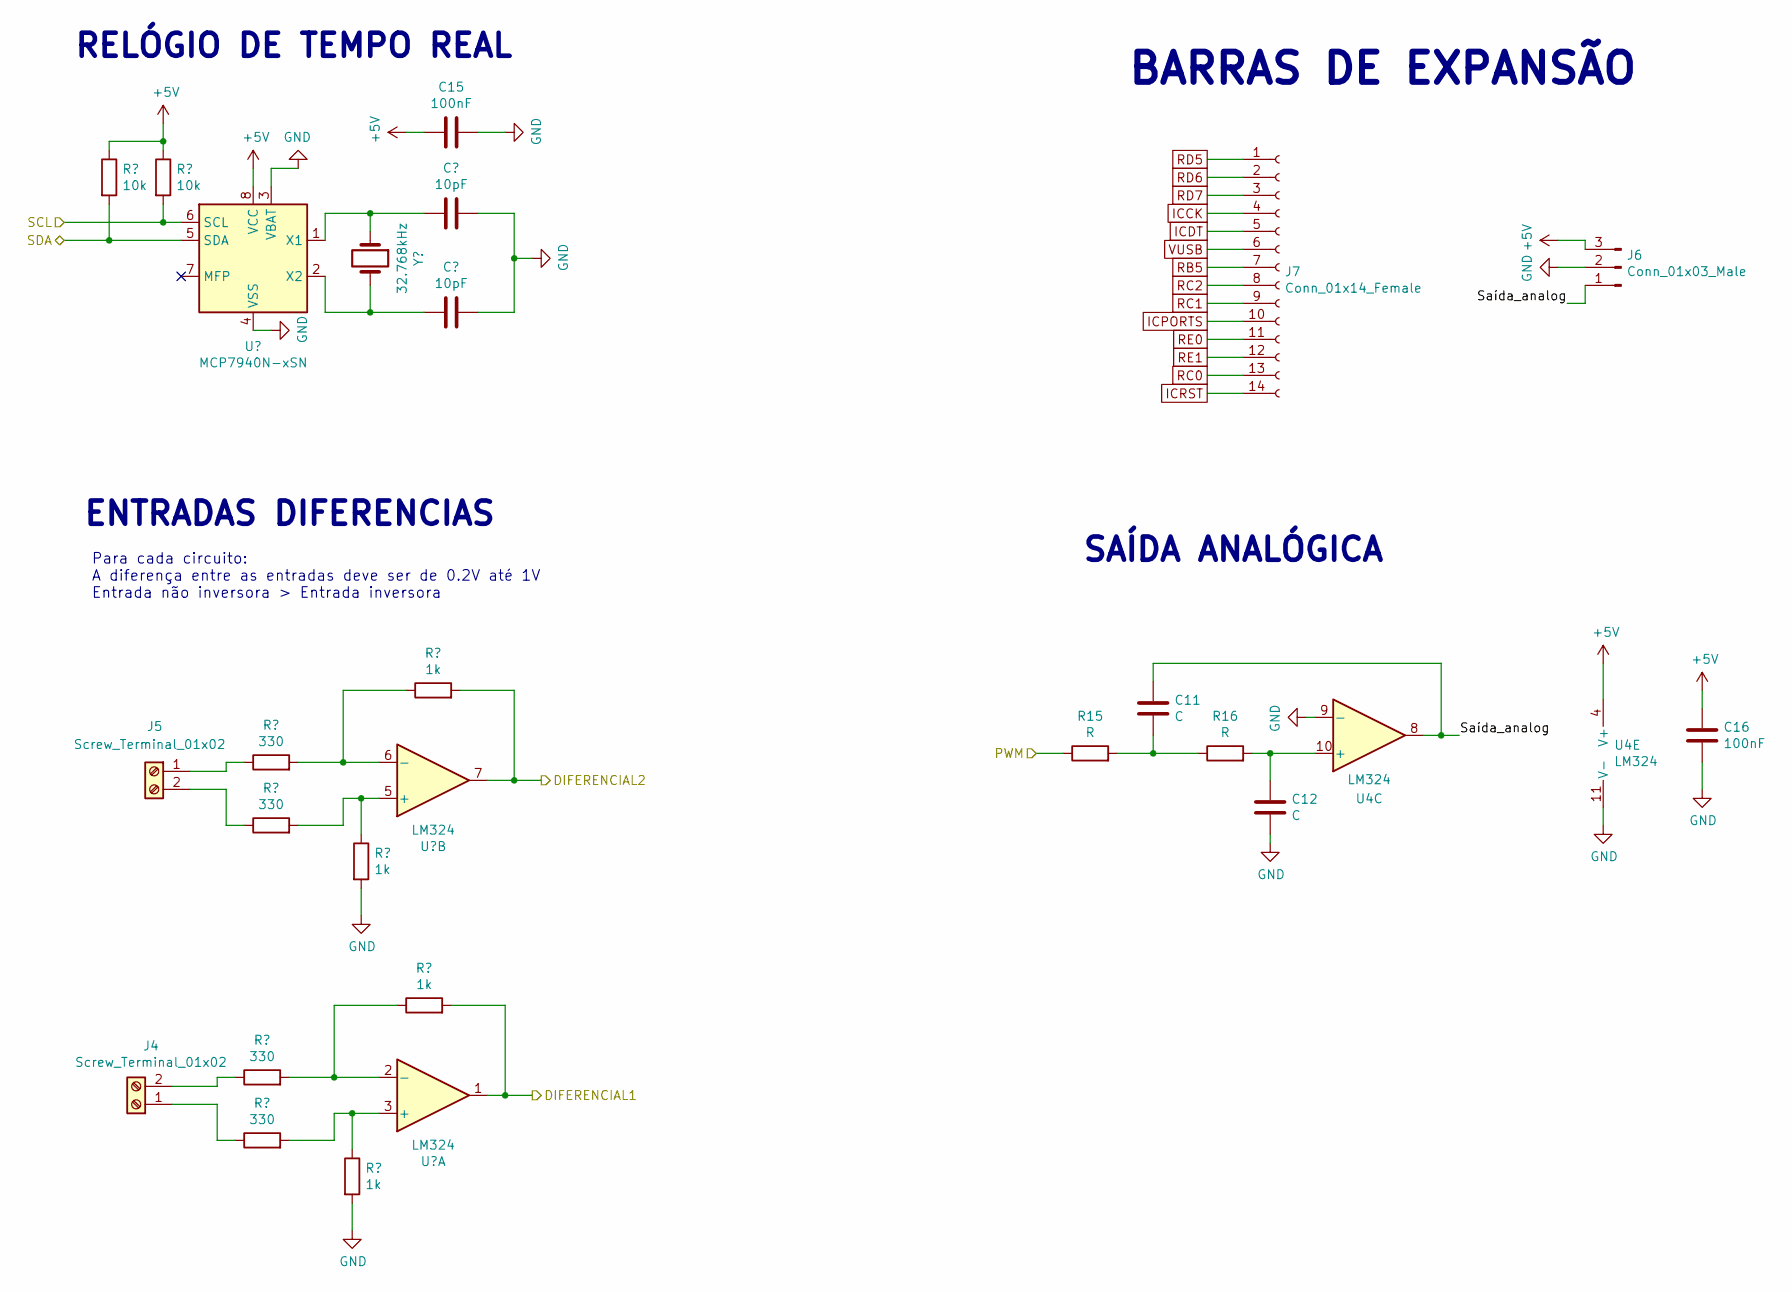
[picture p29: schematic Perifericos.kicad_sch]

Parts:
C9, C10: 10pF; C_0805_2012Metric_Pad1.18x1.45mm_HandSolder
C11, C12: C; C_0805_2012Metric_Pad1.18x1.45mm_HandSolder
C15, C16: 100nF; C_0805_2012Metric_Pad1.18x1.45mm_HandSolder
J4, J5: Screw_Terminal_01x02; TerminalBlock_MetzConnect_Type011_RT05502HBWC_1x02_P5.00mm_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
J6: Conn_01x03_Male; PinHeader_1x03_P2.54mm_Vertical
J7: Conn_01x14_Female; PinSocket_1x14_P2.54mm_Vertical
R5, R6: 10k; R_0805_2012Metric_Pad1.20x1.40mm_HandSolder
R7, R8, R11, R12: 330; R_0805_2012Metric_Pad1.20x1.40mm_HandSolder
R9, R10, R13, R14: 1k; R_0805_2012Metric_Pad1.20x1.40mm_HandSolder
R15, R16: R; R_0805_2012Metric_Pad1.20x1.40mm_HandSolder
U3: MCP7940N-xSN; SOIC127P600X175-8N
U4: LM324; SOIC127P600X175-14N
Y3: 32.768kHz; XTAL_AB38T-32.768KHZ

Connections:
+5V: C15.1, C16.1, J6.3, R5.1, R6.1, U3.8 (VCC), U4.4 (V+); also elsewhere on the board
/DIFERENCIAL1: R9.2, U4.1; also elsewhere on the board
/DIFERENCIAL2: R13.2, U4.7; also elsewhere on the board
/PWM: R15.1; also elsewhere on the board
/SCL: R6.2, U3.6 (SCL); also elsewhere on the board
/SDA: R5.2, U3.5 (SDA); also elsewhere on the board
ICCK: J7.4; also elsewhere on the board
ICDT: J7.5; also elsewhere on the board
ICPORTS: J7.10; also elsewhere on the board
ICRST: J7.14; also elsewhere on the board
unnamed: C9.2, U3.1 (X1), Y3.1
unnamed: C10.1, U3.2 (X2), Y3.2
unnamed: C11.2, R15.2, R16.1
unnamed: C12.1, R16.2, U4.10 (+)
unnamed: J4.1, R8.1
unnamed: J4.2, R7.1
unnamed: J5.1, R11.1
unnamed: J5.2, R12.1
unnamed: R7.2, R9.1, U4.2 (-)
unnamed: R8.2, R10.1, U4.3 (+)
unnamed: R11.2, R13.1, U4.6 (-)
unnamed: R12.2, R14.1, U4.5 (+)
RB5: J7.7; also elsewhere on the board
RC0: J7.13; also elsewhere on the board
RC1: J7.9; also elsewhere on the board
RC2: J7.8; also elsewhere on the board
RD5: J7.1; also elsewhere on the board
RD6: J7.2; also elsewhere on the board
RD7: J7.3; also elsewhere on the board
RE0: J7.11; also elsewhere on the board
RE1: J7.12; also elsewhere on the board
VUSB: J7.6; also elsewhere on the board

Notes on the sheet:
RELÓGIO DE TEMPO REAL
ENTRADAS DIFERENCIAS
BARRAS DE EXPANSÃO
SAÍDA ANALÓGICA
Para cada circuito: A diferença entre as entradas deve ser de 0.2V até 1V Entrada não inversora > Entrada inversora

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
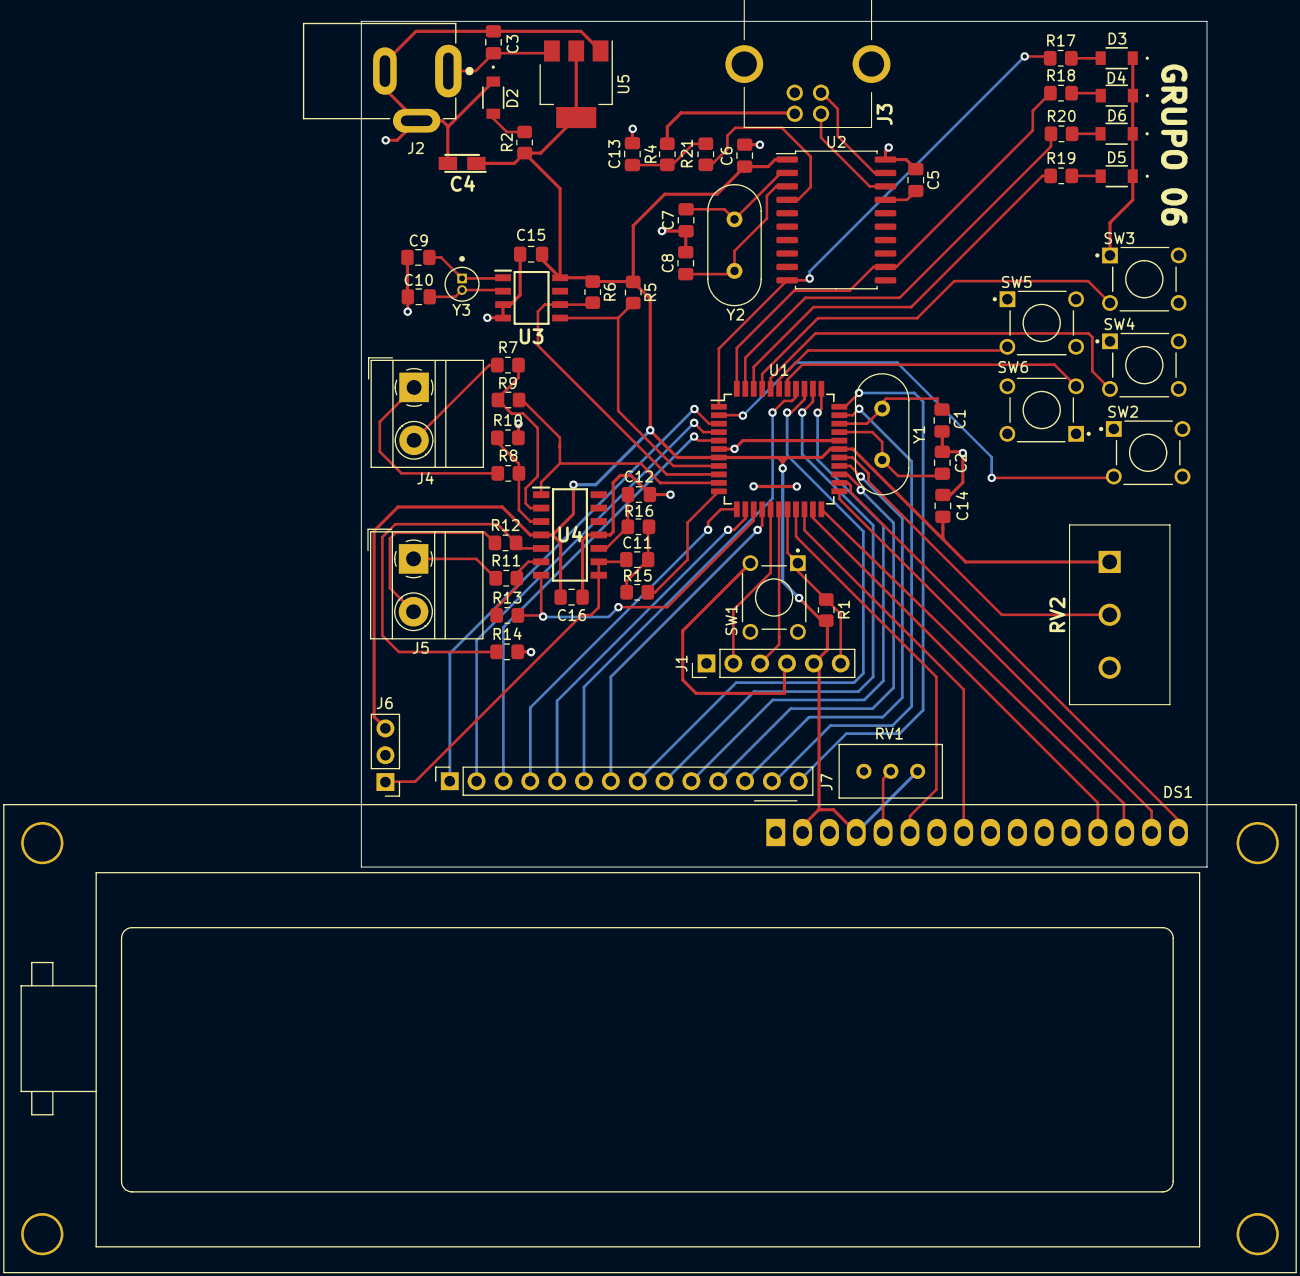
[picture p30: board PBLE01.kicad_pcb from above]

Board: 2 copper layers, 80.0 x 80.0 mm, 65 parts (0 on the bottom side), 70 nets.

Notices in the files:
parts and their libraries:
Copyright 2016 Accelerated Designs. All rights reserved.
